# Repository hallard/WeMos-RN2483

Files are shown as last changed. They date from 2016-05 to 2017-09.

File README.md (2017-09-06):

ESP8266 WeMos Shield for microchip LORAWAN RN2483 or RN2903
===========================================================

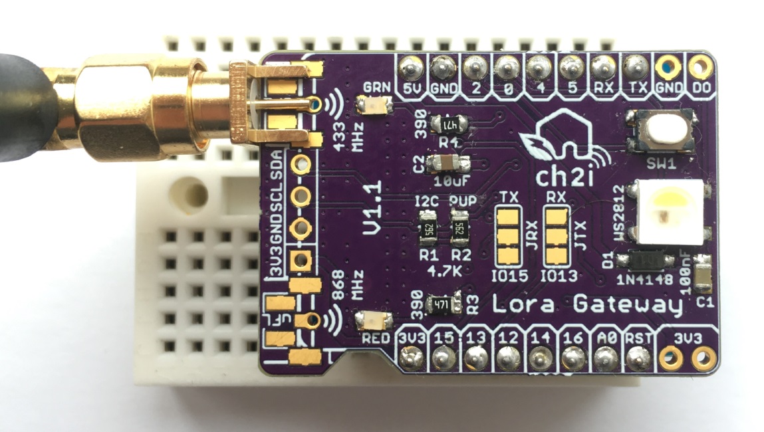
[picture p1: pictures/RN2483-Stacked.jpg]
WeMos With RN2483
 

This shield is used to hold [RN2483][4] Software with WeMos ESP8266 boards it has just few minimal features. 
- I2C Pullups placement
- Classic I2C 128x64 OLED connector
- Placement for Microchip LoraWan [RN2483][4] or [RN2903][4] module
- Placement for choosing single Wire, SMA or u-FL Antenna type for both 433MHz and 868MHz output
- Solder pad choosing 2 RX/TX available on ESP8266 (GPIO1/GPIO3 or GPIO13/GPIO12 to avoid conflict with onboard USB/Serial of WeMos)
- WS2812B Type LED for visual indication
- Custom switch on GPIO14

You can find more information on WeMos on their [site][1], it's really well documented. There is also a nice blog post on Microchip module made by disk91 [here][5]
I now use WeMos boards instead of NodeMCU's one because they're just smaller, features remains the same, but I also suspect WeMos regulator far better quality than the one used on NodeMCU that are just fake of originals AMS117 3V3.

**V1.1 Boards arrived from OSHPark, I tested them, worked out of the box but I made new revision cand corrected some mistakes**
V1.2 contain the following changes (board only, nothing chnaged on schematic):
- Added isolate ground pane to avoid sometime short between header and ground after soldering headers 
- Changed Silk to Node instead of gateway 

**V1.0 Boards arrived from OSHPark, I tested them, worked out of the box but I made new revision cand corrected some mistakes**
V1.1 contain the following changes:
- Error with RX/TX swapped on ESP8266, they are GPIO15/GPIO13 nor GPIO12/GPIO13 (so with V1.0 you can use SoftSerial or Native RX/TX of ESP but not in swapped mode)
- I made larger pad for Microchip module, even if I have strong experience in soldering in SMD, it was a pain to do them see picture below, I suspected board/solder. Ok made some new ones, think now I've got the technique ;-)
- Switch moved from GPIO14 to GPIO2, so I removed pullup because WeMos already have one on GPIO2
- Removed GPIO0 and GPIO11 from RN2483 to avoid as much as possible closer PAD

**V1.1 Boards are tested and working, waiting to test V1.2 but should works, just minor changes**

Detailed Description
====================

Look at the schematics for more informations.

### Firmware

Firmware is currently under developement and may not work as you expected, but for now it works fine for our testing lab.
It's available under [firmware folder][9]. See dedicated [README.md][10].

### Schematic
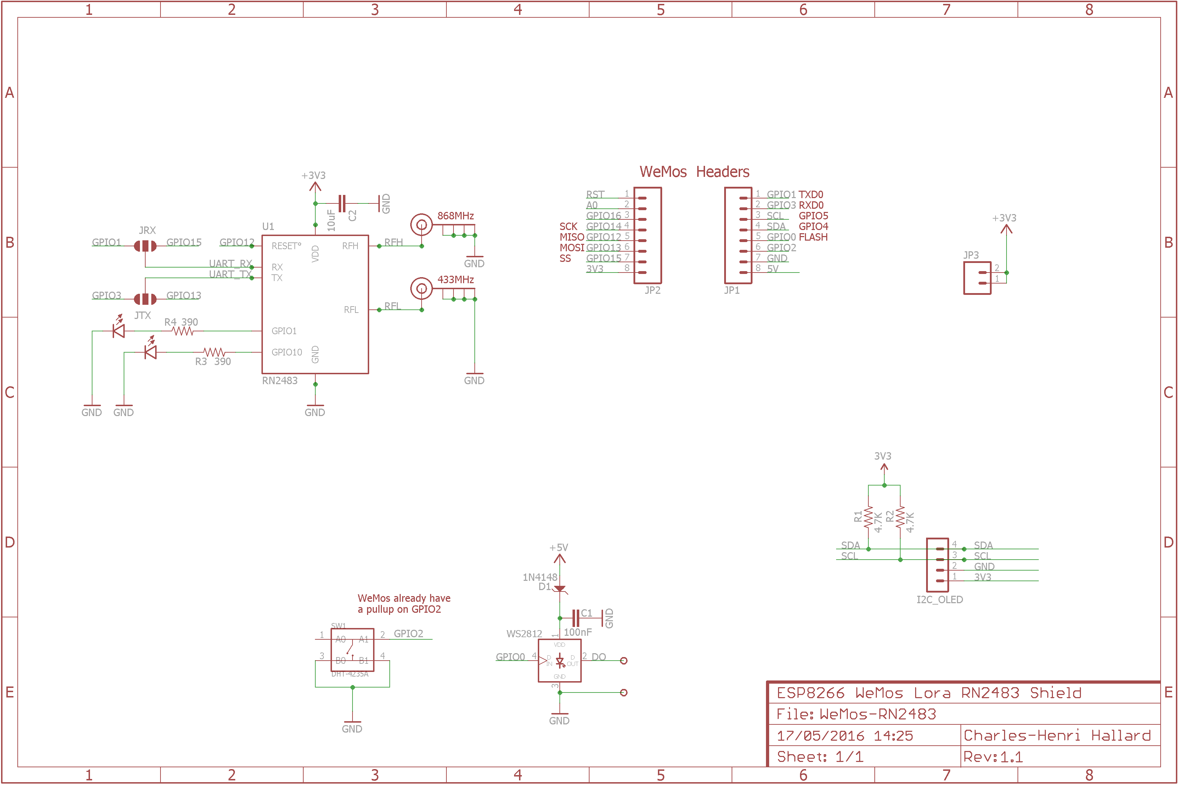
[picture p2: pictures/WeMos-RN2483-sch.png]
schematic
  

### Boards 
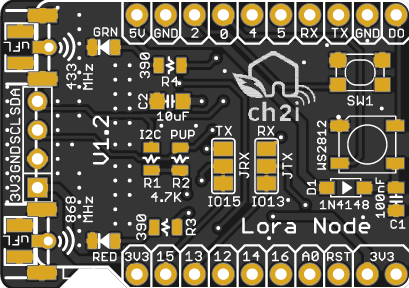
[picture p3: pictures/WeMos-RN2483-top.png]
&nbsp;
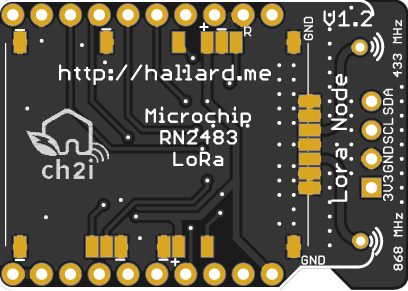
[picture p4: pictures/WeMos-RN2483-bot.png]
&nbsp; 

You can order the PCB of this board at [OSHPARK][3] or at [PCBs.io][8]. But PCBs.io give me reward that allow me to buy some new created boards.

### Assembled boards (V1.0)

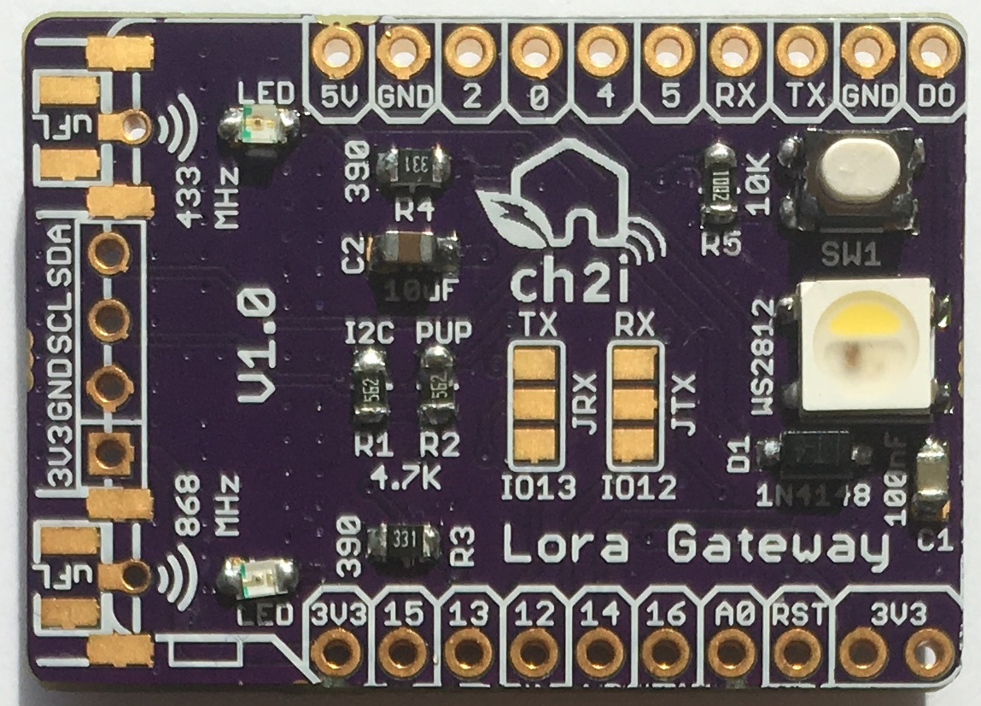
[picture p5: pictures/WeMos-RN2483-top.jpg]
&nbsp;
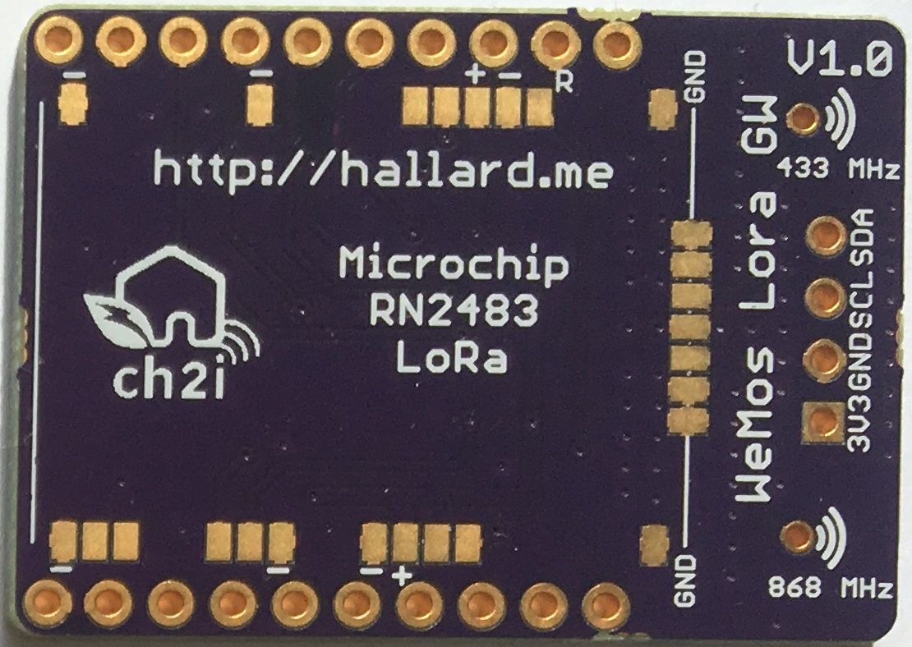
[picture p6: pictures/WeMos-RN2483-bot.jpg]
&nbsp; 
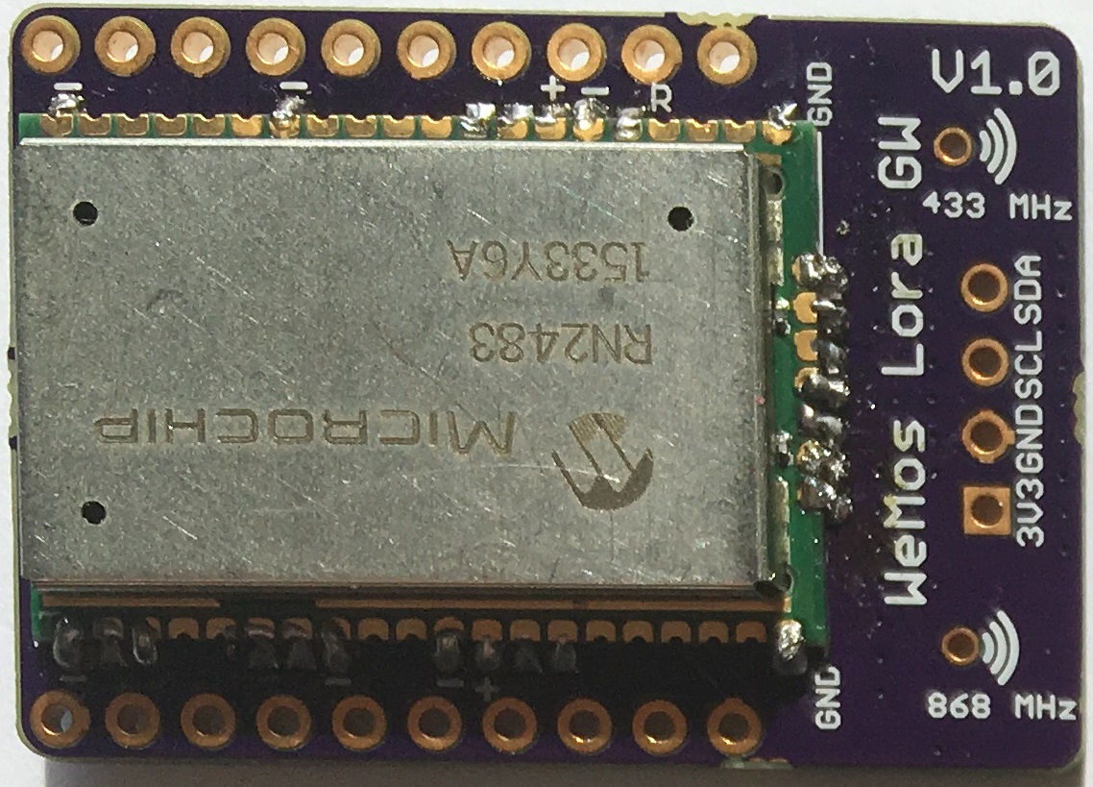
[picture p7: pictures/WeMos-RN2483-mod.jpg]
Bottom With RN2483
&nbsp; 

##License

   

This work is licensed under a [Creative Commons Attribution-NonCommercial 4.0 International License](http://creativecommons.org/licenses/by-nc/4.0/)    
If you want to do commercial stuff with this project, please contact [CH2i company](https://www.ch2i.eu/en#support) so we can organize an simple agreement.

##Misc
See news and other projects on my [blog][2] 
 
[1]: http://www.wemos.cc/Products/d1_mini.html
[2]: https://hallard.me
[3]: https://oshpark.com/shared_projects/G3MI8Wk2
[4]: http://www.microchip.com/wwwproducts/Devices.aspx?product=RN2483
[5]: https://www.disk91.com/2015/technology/networks/first-step-in-lora-land-microchip-rn2483-test/
[6]: https://github.com/hallard/WebSocketToSerial
[7]: http://www.microchip.com/wwwproducts/Devices.aspx?product=RN2903
[8]: https://PCBs.io/share/zMbEp
[9]: https://github.com/hallard/WeMos-RN2483-firmware/tree/master/WeMos-rn2483
[10]: https://github.com/hallard/WeMos-RN2483-firmware/blob/master/WeMos-rn2483/README.md

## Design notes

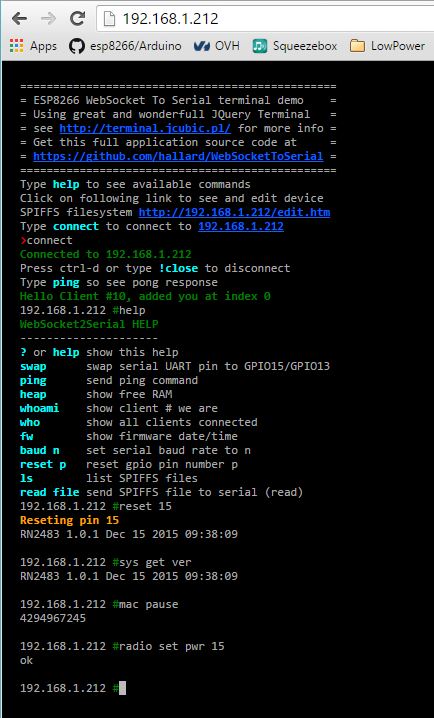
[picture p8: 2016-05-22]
pictures/web-terminal.jpg

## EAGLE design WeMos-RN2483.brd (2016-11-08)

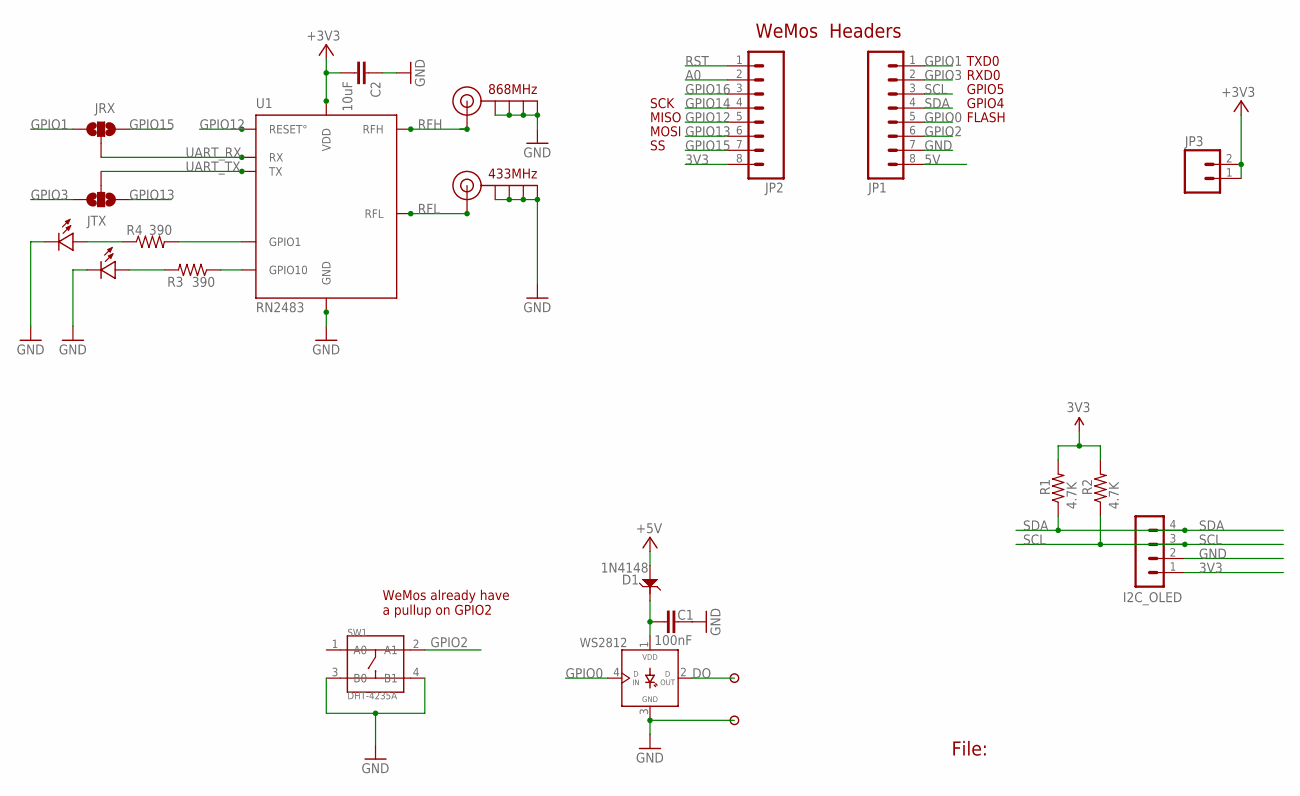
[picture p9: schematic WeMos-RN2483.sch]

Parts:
C1: 100nF; 0805-CAP
C2: 10uF; 0805-CAP-LARGEPADS
D1: 1N4148; SOD123-2.7X1.6
I2C_OLED: CON_HEADER_1X04'SMALL''; M1X4
J$1, J$3: ANTENNASMALL; SMA_UFL_PAD_SMALL
JP1, JP2: M08NO_SILK_FEMALE_PTH; 1X08_NO_SILK
JP3: M021X02_NO_SILK; 1X02_NO_SILK
JRX: JUMPER-PAD-3-NOFULL_BOX_SILK; PAD-JUMPER-3-NO_YES_SILK_FULL_BOX
JTX: JUMPER-PAD-3-NOFULL_BOX_SILK; PAD-JUMPER-3-NO_YES_SILK_FULL_BOX
P2, P3: PADNORMAL; PAD
R1, R2: 4.7K; 0805-RES
R3, R4: 390; 0805-RES
SW1: DHT-4235A; SW4-SMD-4.2X3.2X2.5MM
U1: RN2483; RN2483_4GPIO
U$2: GRN; 0805-LED
U$3: RED; 0805-LED
WS2812: WS2812B

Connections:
3V3: C2.2, I2C_OLED.1, JP2.8, JP3.1, JP3.2, R1.2, R2.2, U1.VDD, U1.VDD2 (VDD)
5V: D1.1, JP1.8
A0: JP2.2
DO: P2.1, WS2812.2 (DOUT)
GND: C1.2, C2.1, I2C_OLED.2, J$1.GND1 (GND), J$1.GND2 (GND), J$1.GND3 (GND), J$1.GND4 (GND), J$3.GND1 (GND), J$3.GND2 (GND), J$3.GND3 (GND), J$3.GND4 (GND), JP1.7, P3.1, SW1.3 (B0), SW1.4 (B1), U1.GND, U1.GND1 (GND), U1.GND2 (GND), U1.GND3 (GND), U1.GND4 (GND), U1.GND5 (GND), U1.GND6 (GND), U1.GND7 (GND), U1.GND8 (GND), U1.GND9 (GND), U1.GND10 (GND), U1.GND11 (GND), U1.GND12 (GND), U$2.MINUS, U$3.MINUS, WS2812.3 (GND)
GPIO0: JP1.5, WS2812.4 (DIN)
GPIO1: JP1.1, JRX.1
GPIO2: JP1.6, SW1.2 (A1)
GPIO3: JP1.2, JTX.3
GPIO12: JP2.5, U1.RESET°
GPIO13: JP2.6, JTX.1
GPIO14: JP2.4
GPIO15: JP2.7, JRX.3
GPIO16: JP2.3
unnamed: R4.2, U1.GPIO1
unnamed: R3.1, U1.GPIO10
unnamed: R3.2, U$3.PLUS
unnamed: R4.1, U$2.PLUS
RFH: J$3.ANT1 (SIGNAL), J$3.ANT2 (SIGNAL), U1.RFH
RFL: J$1.ANT1 (SIGNAL), J$1.ANT2 (SIGNAL), U1.RFL
RST: JP2.1
SCL: I2C_OLED.3, JP1.3, R2.1
SDA: I2C_OLED.4, JP1.4, R1.1
UART_RX: JRX.2, U1.UART_RX (RX)
UART_TX: JTX.2, U1.UART_TX (TX)
VLED: C1.1, D1.2, WS2812.1 (VDD)

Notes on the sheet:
File:
FLASH
MISO
GPIO4
GPIO5
RXD0
TXD0
MOSI
SCK
WeMos Headers
433MHz
868MHz
WeMos already have a pullup on GPIO2

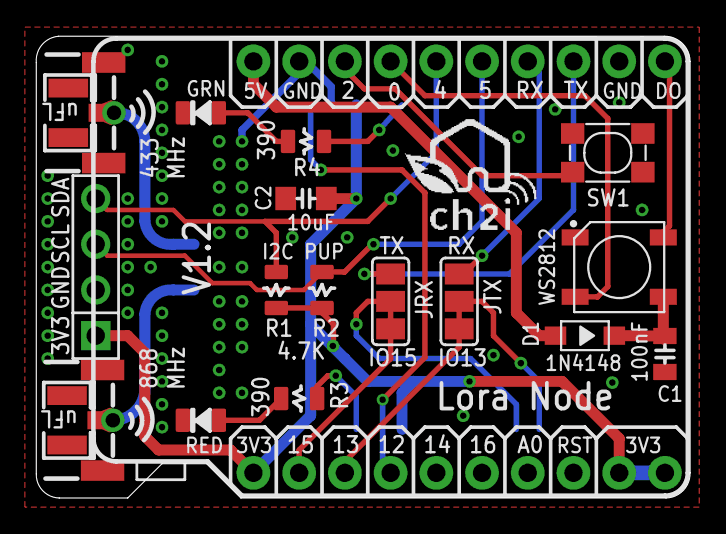
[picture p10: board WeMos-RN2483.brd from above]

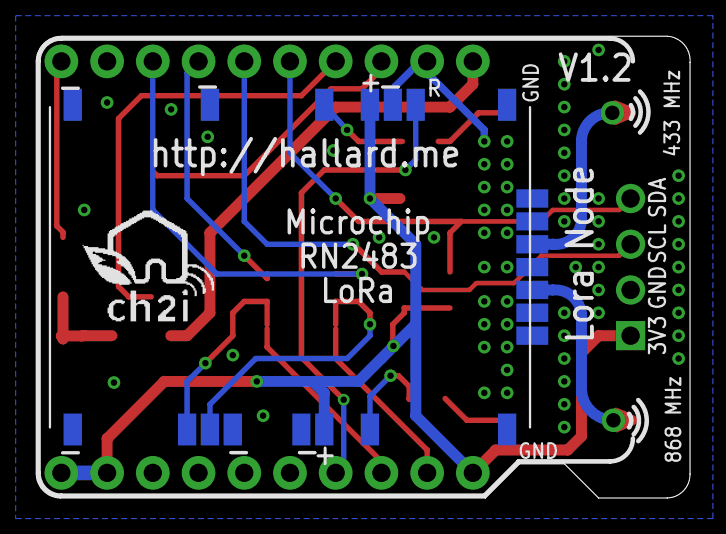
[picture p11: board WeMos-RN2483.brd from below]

Board: 2 copper layers, 36.3 x 25.7 mm, 24 parts (2 on the bottom side), 22 nets.

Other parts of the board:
U$1, U$4: LOGO_CH2I_75MM

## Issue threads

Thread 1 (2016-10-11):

Question about resistors and stuff

ubergesundheit, 2016-10-11:
Hi,

is it enough when I solder on the RN2483 or do I have to solder on the resistors and stuff?

Cheers

hallard, 2016-10-13:
@ubergesundheit
depending on your needs, it should be enough to just solder RN2483 ;-)

ubergesundheit, 2016-10-13:
Excellent! I just need the board to piggyback with the wemos d1 mini. Antenna will be soldered on as a wire..

Closed 2016-10-17.

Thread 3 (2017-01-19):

Add LiPo connector

marcelstoer, 2017-01-19:
I know you described here https://github.com/hallard/NodeMCU-Gateway#nodemcu-esp8266-gateway-goes-to-wemos-esp8266 that this doesn't have a LiPo connector due to size constraints. However, for true autonomy this should really have one 😉
Are you still convinced it ain't possible?

atoy40, 2017-02-11:
@marcelstoer, it exists a wemos mini shield with Lipo connecter and charger.

hallard, 2017-05-23:
@atoy40 is right, Lipo can be not enough because voltage output can vary from 4.2V to 3V so we need to regulate it (wiring it to 5V entry) but would drop voltage at low voltage due to regulator drop out

Closed 2017-08-15.

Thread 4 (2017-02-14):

Via and holes

atoy40, 2017-02-14:
Hello,

Just a question, there is some lines of via/holes on this pcb, is there any reason other than "free-space to fill" :)
I'm creating a Wemos shield with a RN2483 and need more space to put some other stuff on it.

Thanks for help.

hallard, 2017-08-15:
I tried to respect "RN2483" reference design, but to be honest, I think you can remove some but avoid trace under or prox of antenna path

Closed 2017-08-15.

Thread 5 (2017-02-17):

RN2903

ryonlabaw, 2017-02-17:
In order to use this board for the rn2903, one should use the RFH path/antenna?

Comparing the pinout between the rn2483 and rn2903, I notice that the 2903 does not have an RFL out, otherwise it appears to be the same.

Thanks and nice work on the board.

hallard, 2017-08-15:
@ryonlabaw
Correct on RN2903 antenna should go to RFH ;-)

Closed 2017-08-15.

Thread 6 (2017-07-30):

Free D0 for deep sleep

tkerby, 2017-07-30:
In a future revision, I'd like to see the opportunity to wire D0 to RST for deep sleep with a jumper / solder bridge on the board. This would mean moving the WS2812 LED to another pin such as D16

hallard, 2017-08-15:
You can use Deep sleep without any problem, D0 is GPIO16 and this pin is free, Led is on GPIO0 which is D3. So you just need to solder a small wire between pin numbered (on this shield) 16 and RST (pin A0 is in between)

Check Pins_Arduino_h for Wemos Mini D1
```cpp
static const uint8_t D0   = 16;
static const uint8_t D1   = 5;
static const uint8_t D2   = 4;
static const uint8_t D3   = 0;
static const uint8_t D4   = 2;
static const uint8_t D5   = 14;
static const uint8_t D6   = 12;
static const uint8_t D7   = 13;
static const uint8_t D8   = 15;
static const uint8_t RX   = 3;
static const uint8_t TX   = 1;

```

Closed 2017-08-15.

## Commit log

2016-04-26 Changed Name
    [WeMos-RN2483.sch]
2016-05-17 Version V1.1 update
    [WeMos-RN2483.brd, WeMos-RN2483.sch]
2016-06-27 Added picture of assembled board
2016-11-08 Changed silk Gateway to Node
    [WeMos-RN2483.brd]
2016-11-08 Added License and PCBs.io link
2016-11-08 Updated to V1.2
    [WeMos-RN2483.brd, WeMos-RN2483.sch]
2016-11-14 Updated sample config file

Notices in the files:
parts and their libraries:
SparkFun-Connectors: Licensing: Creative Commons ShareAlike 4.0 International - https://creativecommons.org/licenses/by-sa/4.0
